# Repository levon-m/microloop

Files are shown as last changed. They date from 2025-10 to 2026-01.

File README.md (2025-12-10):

# μLoop

μLoop is a standalone **looper & sampler** quantized to external MIDI clock for real-time audio manipulation.\
\
Inspired by French House and Electro sounds, μLoop lets you create immediate **rhythmic glitches** and **sustained textures** with added performance effects.

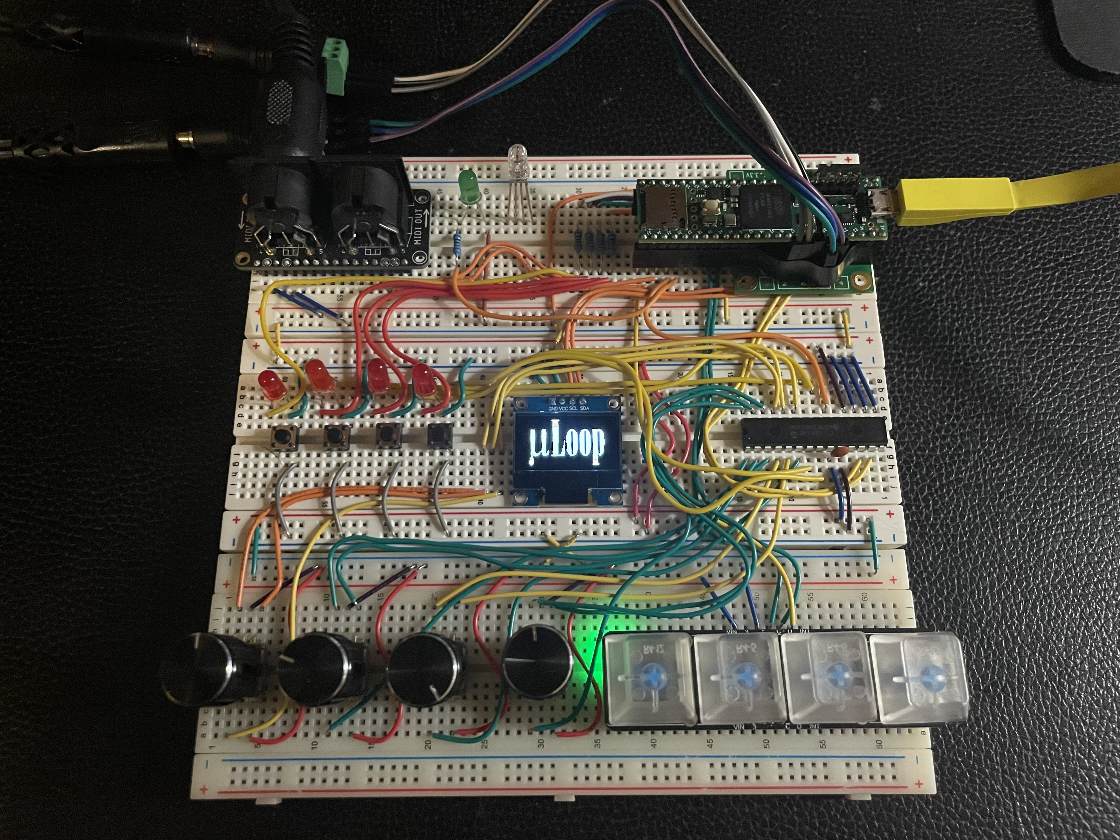
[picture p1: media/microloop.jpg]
MicroLoop Hardware


## Features

#### Effects

- **STUTTER**: Loop buffer that captures and repeats audio slices for glitchy textures
- **FREEZE**: Granular hold effect that captures and sustains a 3ms moment of audio
- **CHOKE**: Instant mute with 3ms crossfades for dramatic cuts and rhythmic gating

#### Control

- **4 Rotary Encoders**: Real-time parameter adjustment for each effect
- **4 Mechanical Switches**: Cherry MX Blue switches with RGB LED feedback
- **4 Preset Buttons**: Access to 4 slots for saving loops via microSD card

#### Interface

- **OLED Display**: Shows effect state, parameter menu system, and settings
- **RGB LED**: Visual feedback for effect states and loop capture
- **Beat LED**: Visualizes incoming jitter-smoothed MIDI clock
- **Preset LEDs**: Visualizes selected preset as well as save/delete operations

#### Timing

- **MIDI Sync**: External MIDI clock sync with <50µs jitter
- **Free & Quantized Modes**: Immediate triggering or synced onset/release for all effects
- **Quantization Grid**: Global beat divisions (1/4, 1/8, 1/16, 1/32 notes)

## Hardware

- Built around the [Teensy 4.1](https://www.pjrc.com/store/teensy41.html) (ARM Cortex-M7 @ 600 MHz)
- Stereo audio I/O via the [Teensy Audio Adapter](https://www.pjrc.com/store/teensy3_audio.html) (SGTL5000 codec @ 44.1 kHz, 16-bit, 128-sample block size)

#### Components

- Teensy 4.1 + Audio Adapter
- Adafruit MIDI FeatherWing
- Adafruit NeoKey 1X4 switches
- SSD1306 128x64 OLED Display
- CYT1100 Rotary Encoders with switches
- MCP23017 I2C I/O expander
- MicroSD Card

#### Interfaces

- **Audio**: Stereo line-in/out via 3.5mm jacks
- **MIDI**: DIN connector
- **I2C**: 3 independent buses for peripherals
- **SDIO**: High-speed 4-bit microSD interface

See [hardware/](hardware/) for full BOM and KiCAD schematics

## Software

#### Signal Flow

- Input -> Timebase -> Stutter -> Freeze -> Choke -> Output

#### Components

- **SGTL5000**: custom register-layer driver for I2C codec configuration
- **Timebase**: Centralized timing authority bridging MIDI clock and audio samples
- **Quantization API**: Sample-accurate for beat/bar-aligned recording and playback
- **Effect System**: Polymorphic command dispatch

#### Architecture

- **Audio ISR**: 128-sample blocks, zero-allocation DSP
- **App Thread**: MIDI clock processing, command dispatch, preset I/O
- **MIDI Thread**: Serial clock reception from DIN connector
- **NeoKey Thread**: Button event handling ISR and RGB LED updates
- **MCP Thread**: 4 rotary encoders via I/O expander interrupts
- **Display Thread**: OLED runtime rendering

#### Design Patterns

- **State Machines**: Deterministic effect transitions with atomic updates
- **Command Pattern**: Type-safe button -> effect communication
- **Registry Pattern**: Dynamic effect lookup and dispatch
- **Observer**: Display subscribes to effect state changes

See [libs/](libs/) for external libraries used

## Technical Highlights

- **Lock-free architecture**: Zero mutexes, all critical paths use atomics + SPSC queues
- **Zero-allocation DSP**: All buffers pre-allocated for deterministic performance
- **Quantization accuracy**: ±11µs (0.5 samples)
- **MIDI jitter**: <50µs (EMA-smoothed BPM)
- **Clean layering**: 4-tier dependency graph (Core -> HAL -> DSP -> App), no upward dependencies

## Build & Flash

#### Prerequisites

- [ARM GNU Toolchain](https://developer.arm.com/downloads/-/arm-gnu-toolchain-downloads) (bare-metal `arm-none-eabi`) 10.3+ on your `PATH`  
- [CMake](https://cmake.org/download/) 3.16+
- [Ninja](https://ninja-build.org/) 1.10+
- Teensy Loader [GUI](https://www.pjrc.com/teensy/loader.html) or [CLI](https://www.pjrc.com/teensy/loader_cli.html)

#### Build

```bash
git clone https://github.com/levon-m/microloop.git
cd microloop

# Configure and build
cmake -S . -B build -G Ninja -DCMAKE_BUILD_TYPE=Release
cmake --build build
```

This produces the firmware file:

```text
build/microloop.hex
```

#### Flash

GUI:

1. Open the Teensy Loader app

2. File -> Open HEX File -> select build/microloop.hex

3. Connect the Teensy and press Program (or the BOOT button if prompted)

CLI:

```bash
cd build
teensy_loader_cli --mcu=TEENSY41 -w microloop.hex
```

Press the Teensy BOOT button once if it doesn’t auto-detect

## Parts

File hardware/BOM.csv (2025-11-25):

Item | Quantity | RefDes | MFR / Source | MFR PN / Link | DigiKey PN | ~Price
Teensy 4.1 (with header pins) | 1 | U1 | SparkFun Electronics | 28370 | 1568-28370-ND | $29.50
Teensy Audio Adapter board Rev D | 1 | U2 | SparkFun Electronics | 15845 | 1568-15845-ND | $9.80
8 MB PSRAM chip | 1 |  | SparkFun Electronics | COM-28391 | 1568-COM-28391-ND | $2.25
MIDI FeatherWing kit | 1 | U3 | Adafruit Industries LLC | 4740 | 1528-4740-ND | $6.95
NeoKey 1X4 mechanical key switch board w/ LEDs | 1 | U7 | Adafruit Industries LLC | 4980 | 1528-4980-ND | $9.95
Cherry MX Blue switches (5-pin, transparent) | 4 |  | Cherry Americas LLC | MX2A-E1NB | 1644-MX2A-E1NB-ND | $7.00
Translucent keycaps | 1 |  | Adafruit Industries LLC | 4956 | 1528-4956-ND | $4.95
MCP23017 I2C I/O expander | 1 | U5 | Microchip Technology | MCP23017-E/SP | MCP23017-E/SP-ND | $1.69
Rotary encoders with push buttons (20 detents) + knob caps | 1 | SW1, SW2, SW3, SW4 | Amazon | https://www.amazon.com/dp/B07DM2YMT4 |  | $8.89
128GB microSD card (can go as low as 8GB) | 1 |  | Amazon | https://www.amazon.com/dp/B0B7NTY2S6 |  | $16.99
OLED I2C module (monochrome white, 128x64) | 1 | U6 | Amazon | https://www.amazon.com/dp/B09JWN8K99 |  | $12.99
Stackable (long-tail) headers | 1 |  | Amazon | https://www.amazon.com/dp/B0778M5P1W |  | $6.99
3.5mm stereo jacks to screw terminals | 1 | J1, J2 | Amazon | https://www.amazon.com/dp/B017CBTLJK |  | $5.79
Tactile Switches | 4 | SW5, SW6, SW7, SW8 | TE Connectivity ALCOSWITCH Switches | 1825910-6 | 450-1650-ND | $0.52
Green LED | 1 | D2 | Lite-On Inc. | LTL-307GE | 160-1702-ND | $0.19
Red LEDs | 4 | D3, D4, D5, D6 | Lite-On Inc. | LTL-307EE | 160-1701-ND | $0.76
RGB LED | 1 | D1 | Inolux | HV-5RGB60 | 1830-1014-ND | $1.06
330 Ohm Resistors | 8 | R1, R2, R3, R4, R5, R6, R7, R8 | Stackpole Electronics Inc | CF14JT330R | CF14JT330RCT-ND | $0.60
100 nF Capacitor | 1 | C1 | Vishay Beyschlag/Draloric/BC Components | K104K15X7RF5TL2 | BC1084CT-ND | $0.25
 |  |  |  |  |  | $127

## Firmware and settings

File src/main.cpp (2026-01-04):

#include <Arduino.h>
#include <Audio.h>
#include <TeensyThreads.h>
#include "MidiInput.h"
#include "App.h"
#include "NeokeyInput.h"
#include "Ssd1306Display.h"
#include "Mcp23017Input.h"
#include "SdCardStorage.h"
#include "FreezeAudio.h"
#include "ChokeAudio.h"
#include "StutterAudio.h"
#include "EffectManager.h"
#include "Trace.h"
#include "Timebase.h"
#include "TimebaseAudio.h"

AudioInputI2S i2s_in;
TimebaseAudio timekeeper;  // Tracks sample position
FreezeAudio freeze;    // Circular buffer freeze effect
ChokeAudio choke;      // Smooth mute effect
StutterAudio stutter;
AudioOutputI2S i2s_out;
// MOTU 3/4 line input gains are fixed and very insensitive, hearing noise floor without a boost
//AudioAmplifier outGainL;
//AudioAmplifier outGainR;

// Audio connections (stereo L+R)
AudioConnection patchCord1(i2s_in, 0, timekeeper, 0);
AudioConnection patchCord2(i2s_in, 1, timekeeper, 1);
AudioConnection patchCord3(timekeeper, 0, stutter, 0);
AudioConnection patchCord4(timekeeper, 1, stutter, 1);
AudioConnection patchCord5(stutter, 0, freeze, 0);
AudioConnection patchCord6(stutter, 1, freeze, 1);
AudioConnection patchCord7(freeze, 0, choke, 0);
AudioConnection patchCord8(freeze, 1, choke, 1);
AudioConnection patchCord9(choke, 0, i2s_out, 0);
AudioConnection patchCord10(choke, 1, i2s_out, 1);
//AudioConnection patchCord11(outGainL, 0, i2s_out, 0);
//AudioConnection patchCord12(outGainR, 0, i2s_out, 1);


// Teensy Audio Library SGTL5000 control
AudioControlSGTL5000 codec;

// Global thread IDs for debugging
int g_ioThreadId = -1;
int g_inputThreadId = -1;
int g_mcpThreadId = -1;
int g_displayThreadId = -1;
int g_appThreadId = -1;

// SD operation request from thread to main loop
// threads.stop()/start() MUST be called from main loop, not from within a thread
volatile bool g_sdOperationPending = false;
volatile uint8_t g_sdOperationSlot = 0;
volatile int g_sdOperationType = 0; // 0=none, 1=save, 2=load, 3=delete
volatile bool g_sdOperationComplete = false;
volatile int g_sdOperationResult = 0;

void ioThreadEntry() {
    MidiInput::threadLoop();  // Never returns
}

void inputThreadEntry() {
    NeokeyInput::threadLoop();  // Never returns
}

void mcpThreadEntry() {
    Mcp23017Input::threadLoop();  // Never returns
}

void displayThreadEntry() {
    Ssd1306Display::threadLoop();  // Never returns
}

void appThreadEntry() {
    App::threadLoop();  // Never returns
}

void setup() {
    Serial.begin(115200);

    // Print crash report if available (from previous run)
    // DEBUGGING AID: If Teensy crashed, this tells us why
    if (CrashReport) {
        Serial.print(CrashReport);
    }

    Serial.println("=== MicroLoop Initializing ===");

    AudioMemory(60);

    if (!codec.enable()) {
        Serial.println("ERROR: Codec init failed!");
        while (1) {
            // Blink LED rapidly to indicate error
            digitalWrite(LED_BUILTIN, !digitalRead(LED_BUILTIN));
            delay(100);
        }
    }

    // Configure for line-in and line-out operation
    // IMPORTANT: Use MOTU M4 **REAR LINE INPUTS 3-4** (not front combo jacks!)
    codec.inputSelect(AUDIO_INPUT_LINEIN);  // Use line-in (not mic)
    codec.micGain(0);
    codec.lineInLevel(0);  // Line-in gain: 0-15 (0 = 3.12V p-p, lowest gain to prevent clipping)
    codec.lineOutLevel(13);  // Line-out level: 13-31 (13 = 1.31V p-p, standard line level)
    codec.unmuteLineout();  // Unmute line-out
    codec.volume(0.7);  // Headphone volume (0.0-1.0) - start low to avoid clipping
    codec.unmuteHeadphone();  // Unmute headphone (for testing)
    //outGainL.gain(1.0f);   // try 1.5 to 3.0
    //outGainR.gain(1.0f);

    Serial.println("Audio: OK (using Teensy Audio Library SGTL5000)");

    Timebase::begin();
    Serial.println("TimeKeeper: OK");

    MidiInput::begin();
    Serial.println("MIDI: OK (DIN on Serial8)");

    // Initialize SD card BEFORE App::begin() (PresetController needs it)
    if (!SdCardStorage::begin()) {
        Serial.println("WARNING: SD card init failed (presets disabled)");
        // Continue anyway - SD card is optional for basic functionality
    } else {
        Serial.println("SD Card: OK (SDIO)");
    }

    App::begin();
    Serial.println("App Logic: OK");

    if (!NeokeyInput::begin()) {
        Serial.println("ERROR: NeoKey I/O init failed!");
        while (1) {
            // Blink LED rapidly to indicate error
            digitalWrite(LED_BUILTIN, !digitalRead(LED_BUILTIN));
            delay(100);
        }
    }
    Serial.println("NeoKey I/O: OK (Neokey on I2C 0x30 / Wire2)");

    if (!Mcp23017Input::begin()) {
        Serial.println("ERROR: MCP I/O init failed!");
        while (1) {
            // Blink LED rapidly to indicate error
            digitalWrite(LED_BUILTIN, !digitalRead(LED_BUILTIN));
            delay(100);
        }
    }
    Serial.println("MCP I/O: OK (MCP23017 on I2C 0x20 / Wire, ISR capture mode)");

    if (!Ssd1306Display::begin()) {
        Serial.println("WARNING: Display init failed (will continue without display)");
        // Continue anyway - display is optional for basic functionality
    } else {
        Serial.println("Display: OK (SSD1306 on I2C 0x3C / Wire1)");
    }

    if (!EffectManager::registerEffect(EffectID::STUTTER, &stutter)) {
        Serial.println("FATAL: Failed to register stutter effect!");
        while (1) {
            // Blink LED rapidly to indicate error
            digitalWrite(LED_BUILTIN, !digitalRead(LED_BUILTIN));
            delay(100);
        }
    }
    if (!EffectManager::registerEffect(EffectID::FREEZE, &freeze)) {
        Serial.println("FATAL: Failed to register freeze effect!");
        while (1) {
            // Blink LED rapidly to indicate error
            digitalWrite(LED_BUILTIN, !digitalRead(LED_BUILTIN));
            delay(100);
        }
    }
    if (!EffectManager::registerEffect(EffectID::CHOKE, &choke)) {
        Serial.println("FATAL: Failed to register choke effect!");
        while (1) {
            // Blink LED rapidly to indicate error
            digitalWrite(LED_BUILTIN, !digitalRead(LED_BUILTIN));
            delay(100);
        }
    }
    Serial.print("Effect Manager: Registered ");
    Serial.print(EffectManager::getNumEffects());
    Serial.println(" effect(s)");

    g_ioThreadId = threads.addThread(ioThreadEntry, 0, 2048);
    g_inputThreadId = threads.addThread(inputThreadEntry, 0, 2048);
    g_mcpThreadId = threads.addThread(mcpThreadEntry, 0, 2048);
    g_displayThreadId = threads.addThread(displayThreadEntry, 0, 2048);
    // 16KB stack: App thread runs blocking SD save/load/delete operations
    g_appThreadId = threads.addThread(appThreadEntry, 0, 16384);

    if (g_ioThreadId < 0 || g_inputThreadId < 0 || g_mcpThreadId < 0 || g_displayThreadId < 0 || g_appThreadId < 0) {
        Serial.println("ERROR: Thread creation failed!");
        while (1);  // Halt
    }

    // threads.setTimeSlice(ioThreadId, 2);   // 2ms - very responsive
    // threads.setTimeSlice(appThreadId, 5);  // 5ms - moderate

    Serial.println("Threads: Started");
    Serial.println("=== MicroLoop Running ===");
    Serial.println();
    Serial.println("Commands:");
    Serial.println("  't' - Dump trace buffer");
    Serial.println("  'c' - Clear trace buffer");
    Serial.println("  's' - Show TimeKeeper status");
    Serial.println();
}

void loop() {
    // Thread state monitoring - print every second
    static uint32_t lastThreadStatePrint = 0;
    if (millis() - lastThreadStatePrint >= 1000) {
        lastThreadStatePrint = millis();

        auto printState = [](const char* name, int id) {
            Serial.print(" ");
            Serial.print(name);
            Serial.print("=");
            if (id >= 0) {
                int state = threads.getState(id);
                Serial.print(state);
                // Decode state: 0=RUNNING, 1=SUSPENDED, 2=ENDED, etc.
                Serial.print("(");
                switch(state) {
                    case 0: Serial.print("RUN"); break;
                    case 1: Serial.print("SUSP"); break;
                    case 2: Serial.print("END"); break;
                    default: Serial.print("???"); break;
                }
                Serial.print(")");
            } else {
                Serial.print("N/A");
            }
        };

        Serial.print("[ThreadStates] T=");
        Serial.print(millis());
        printState(" app", g_appThreadId);
        printState(" io", g_ioThreadId);
        printState(" nk", g_inputThreadId);
        printState(" mcp", g_mcpThreadId);
        printState(" disp", g_displayThreadId);
        Serial.println();
    }

    // Check for serial commands (non-blocking)
    if (Serial.available()) {
        char cmd = Serial.read();
        switch (cmd) {
            case 't':  // Dump trace buffer
                Serial.println("\n[Dumping trace buffer...]");
                Trace::dump();
                break;

            case 'c':  // Clear trace buffer
                Serial.println("\n[Clearing trace buffer...]");
                Trace::clear();
                Serial.println("Trace buffer cleared.");
                break;

            case 's':  // Show TimeKeeper status
                Serial.println("\n=== TimeKeeper Status ===");
                Serial.print("Sample Position: ");
                Serial.println((uint32_t)Timebase::getSamplePosition());  // Print low 32 bits
                Serial.print("Beat: ");
                Serial.print(Timebase::getBeatNumber());
                Serial.print(" (Bar ");
                Serial.print(Timebase::getBarNumber());
                Serial.print(", Beat ");
                Serial.print(Timebase::getBeatInBar());
                Serial.print(", Tick ");
                Serial.print(Timebase::getTickInBeat());
                Serial.println(")");
                Serial.print("BPM: ");
                Serial.println(Timebase::getBPM(), 2);
                Serial.print("Samples/Beat: ");
                Serial.println(Timebase::getSamplesPerBeat());
                Serial.print("Transport: ");
                switch (Timebase::getTransportState()) {
                    case Timebase::TransportState::STOPPED: Serial.println("STOPPED"); break;
                    case Timebase::TransportState::PLAYING: Serial.println("PLAYING"); break;
                    case Timebase::TransportState::RECORDING: Serial.println("RECORDING"); break;
                }
                Serial.print("Samples to next beat: ");
                Serial.println(Timebase::samplesToNextBeat());
                Serial.print("Samples to next bar: ");
                Serial.println(Timebase::samplesToNextBar());
                Serial.println("=========================\n");
                break;

            case '\n':
            case '\r':
                // Ignore newlines
                break;

            default:
                Serial.print("Unknown command: ");
                Serial.println(cmd);
                Serial.println("Commands: 't' (dump trace), 'c' (clear trace), 's' (status)");
                break;
        }
    }

    delay(10);  // Don't hog CPU
}

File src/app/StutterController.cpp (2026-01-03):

#include "StutterController.h"
#include "NeokeyInput.h"
#include "DisplayManager.h"
#include "Timebase.h"
#include "EncoderHandler.h"
#include <Arduino.h>

// ========== RGB LED PIN DEFINITIONS ==========
static constexpr uint8_t RGB_LED_R_PIN = 28;  // Red (PWM capable)
static constexpr uint8_t RGB_LED_G_PIN = 36;  // Green (PWM capable)
static constexpr uint8_t RGB_LED_B_PIN = 37;  // Blue (PWM capable)

// ========== GAMMA LOOKUP TABLE (γ=4.0) ==========
// Pre-computed gamma curve for dramatic LED brightness ramp.
// Input: linear progress 0-255, Output: gamma-corrected brightness 0-255
// Formula: output = 255 * (input/255)^4.0
// Characteristic: stays dim until ~80%, then rapid ramp in final ~20%
static constexpr uint8_t GAMMA_LUT[256] = {
      0,   0,   0,   0,   0,   0,   0,   0,   0,   0,   0,   0,   0,   0,   0,   0,
      0,   0,   0,   0,   0,   0,   0,   0,   0,   0,   0,   0,   0,   0,   0,   0,
      0,   0,   0,   0,   0,   0,   0,   0,   0,   0,   0,   0,   0,   0,   0,   0,
      0,   0,   0,   0,   0,   0,   0,   0,   0,   0,   0,   0,   0,   0,   0,   0,
      0,   0,   0,   0,   0,   0,   0,   0,   0,   0,   0,   1,   1,   1,   1,   1,
      1,   1,   1,   1,   1,   1,   1,   1,   1,   1,   2,   2,   2,   2,   2,   2,
      2,   2,   3,   3,   3,   3,   3,   3,   4,   4,   4,   4,   4,   5,   5,   5,
      5,   6,   6,   6,   6,   7,   7,   7,   8,   8,   8,   9,   9,   9,  10,  10,
     11,  11,  11,  12,  12,  13,  13,  14,  14,  15,  15,  16,  17,  17,  18,  18,
     19,  20,  20,  21,  22,  22,  23,  24,  25,  25,  26,  27,  28,  29,  30,  31,
     31,  32,  33,  34,  35,  36,  38,  39,  40,  41,  42,  43,  45,  46,  47,  48,
     50,  51,  52,  54,  55,  57,  58,  60,  61,  63,  64,  66,  68,  69,  71,  73,
     75,  76,  78,  80,  82,  84,  86,  88,  90,  92,  94,  96,  98, 100, 103, 105,
    107, 109, 112, 114, 117, 119, 122, 124, 127, 129, 132, 135, 137, 140, 143, 146,
    149, 151, 154, 157, 160, 163, 166, 170, 173, 176, 179, 182, 186, 189, 192, 196,
    199, 203, 206, 210, 214, 217, 221, 225, 228, 232, 236, 240, 244, 248, 252, 255
};

/**
 * Calculate LED brightness for wait states using gamma-corrected ramp
 *
 * @param currentSample Current audio sample position
 * @param startSample Sample position when wait began
 * @param targetSample Sample position when wait will end
 * @param rampUp true = 0→max (onset waits), false = max→0 (end waits)
 * @return Gamma-corrected brightness value 0-255
 */
static uint8_t calculateWaitBrightness(uint64_t currentSample, uint64_t startSample,
                                       uint64_t targetSample, bool rampUp) {
    // Safety checks
    if (targetSample <= startSample) return rampUp ? 255 : 0;
    if (currentSample <= startSample) return rampUp ? 0 : 255;
    if (currentSample >= targetSample) return rampUp ? 255 : 0;

    // Calculate linear progress (0-255 range for LUT indexing)
    uint64_t elapsed = currentSample - startSample;
    uint64_t total = targetSample - startSample;
    uint8_t linearProgress = static_cast<uint8_t>((elapsed * 255) / total);

    // Apply gamma curve
    uint8_t gammaBrightness = GAMMA_LUT[linearProgress];

    // Invert for ramp down
    return rampUp ? gammaBrightness : (255 - gammaBrightness);
}

StutterController::StutterController(StutterAudio& effect)
    : m_effect(effect),
      m_currentParameter(Parameter::ONSET),  // Default to ONSET (first in cycle)
      m_funcHeld(false),
      m_stutterHeld(false),
      m_wasEnabled(false),
      m_captureCompleteCallback(nullptr),
      m_lastState(StutterState::IDLE_NO_LOOP),
      m_captureInProgress(false) {
}

BitmapID StutterController::stateToBitmap(StutterState state) {
    // Only show STUTTER_ACTIVE during playback states
    switch (state) {
        case StutterState::PLAYING:
        case StutterState::WAIT_PLAYBACK_LENGTH:
            return BitmapID::STUTTER_ACTIVE;
        default:
            return BitmapID::DEFAULT;  // All other states (idle, capture, wait onset)
    }
}

const char* StutterController::onsetName(StutterOnset onset) {
    switch (onset) {
        case StutterOnset::FREE:      return "Free";
        case StutterOnset::QUANTIZED: return "Quantized";
        default: return "Free";
    }
}

const char* StutterController::lengthName(StutterLength length) {
    switch (length) {
        case StutterLength::FREE:      return "Free";
        case StutterLength::QUANTIZED: return "Quantized";
        default: return "Free";
    }
}

const char* StutterController::captureStartName(StutterCaptureStart captureStart) {
    switch (captureStart) {
        case StutterCaptureStart::FREE:      return "Free";
        case StutterCaptureStart::QUANTIZED: return "Quantized";
        default: return "Free";
    }
}

const char* StutterController::captureEndName(StutterCaptureEnd captureEnd) {
    switch (captureEnd) {
        case StutterCaptureEnd::FREE:      return "Free";
        case StutterCaptureEnd::QUANTIZED: return "Quantized";
        default: return "Free";
    }
}

// ========== BUTTON PRESS HANDLER ==========
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

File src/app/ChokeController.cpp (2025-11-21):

#include "ChokeController.h"
#include "NeokeyInput.h"
#include "DisplayManager.h"
#include "Timebase.h"
#include "EncoderHandler.h"
#include <Arduino.h>

ChokeController::ChokeController(ChokeAudio& effect)
    : m_effect(effect),
      m_currentParameter(Parameter::LENGTH),
      m_wasEnabled(false) {
}

const char* ChokeController::lengthName(ChokeLength length) {
    switch (length) {
        case ChokeLength::FREE:      return "Free";
        case ChokeLength::QUANTIZED: return "Quantized";
        default: return "Free";
    }
}

const char* ChokeController::onsetName(ChokeOnset onset) {
    switch (onset) {
        case ChokeOnset::FREE:      return "Free";
        case ChokeOnset::QUANTIZED: return "Quantized";
        default: return "Free";
    }
}

bool ChokeController::handleButtonPress(const Command& cmd) {
    if (cmd.targetEffect != EffectID::CHOKE) {
        return false;  // Not our effect
    }

    if (cmd.type != CommandType::EFFECT_ENABLE && cmd.type != CommandType::EFFECT_TOGGLE) {
        return false;  // Not a press command
    }

    ChokeLength lengthMode = m_effect.getLengthMode();
    ChokeOnset onsetMode = m_effect.getOnsetMode();

    if (onsetMode == ChokeOnset::FREE) {
        // FREE ONSET: Engage immediately
        m_effect.enable();

        if (lengthMode == ChokeLength::QUANTIZED) {
            // FREE ONSET + QUANTIZED LENGTH
            Quantization quant = EffectQuantization::getGlobalQuantization();
            uint32_t durationSamples = EffectQuantization::calculateQuantizedDuration(quant);
            uint64_t releaseSample = Timebase::getSamplePosition() + durationSamples;
            m_effect.scheduleRelease(releaseSample);

            Serial.print("Choke ENGAGED (Free onset, Quantized length=");
            Serial.print(EffectQuantization::quantizationName(quant));
            Serial.println(")");
        } else {
            // FREE ONSET + FREE LENGTH
            Serial.println("Choke ENGAGED (Free onset, Free length)");
        }

        // Update visual feedback
        NeokeyInput::setLED(EffectID::CHOKE, true);
        DisplayManager::instance().updateDisplay();
        return true;  // Command handled
    } else {
        // QUANTIZED ONSET: Schedule for next boundary with lookahead offset
        Quantization quant = EffectQuantization::getGlobalQuantization();

        // DEBUG: Get all timing info
        uint64_t currentSample = Timebase::getSamplePosition();
        uint32_t samplesPerBeat = Timebase::getSamplesPerBeat();
        uint32_t beatNumber = Timebase::getBeatNumber();
        uint32_t tickInBeat = Timebase::getTickInBeat();

        uint32_t samplesToNext = EffectQuantization::samplesToNextQuantizedBoundary(quant);

        // Apply lookahead offset (fire early to catch external audio transients)
        uint32_t lookahead = EffectQuantization::getLookaheadOffset();
        uint32_t adjustedSamples = (samplesToNext > lookahead) ? (samplesToNext - lookahead) : 0;

        // Calculate absolute sample position for onset
        uint64_t onsetSample = currentSample + adjustedSamples;

        // Schedule onset in ISR (same as how length scheduling works)
        m_effect.scheduleOnset(onsetSample);

        // If length is also quantized, schedule release from onset position
        if (lengthMode == ChokeLength::QUANTIZED) {
            uint32_t durationSamples = EffectQuantization::calculateQuantizedDuration(quant);
            uint64_t releaseSample = onsetSample + durationSamples;
            m_effect.scheduleRelease(releaseSample);
        }

        Serial.print("ONSET DEBUG: currentSample=");
        Serial.print((uint32_t)currentSample);
        Serial.print(" beat=");
        Serial.print(beatNumber);
        Serial.print(" tick=");
        Serial.print(tickInBeat);
        Serial.print(" spb=");
        Serial.print(samplesPerBeat);
        Serial.print(" samplesToNext=");
        Serial.print(samplesToNext);
        Serial.print(" lookahead=");
        Serial.print(lookahead);
        Serial.print(" adjusted=");
        Serial.print(adjustedSamples);
        Serial.print(" onsetSample=");
        Serial.println((uint32_t)onsetSample);

        return true;  // Command handled
    }
}

bool ChokeController::handleButtonRelease(const Command& cmd) {
    if (cmd.targetEffect != EffectID::CHOKE) {
        return false;  // Not our effect
    }

    if (cmd.type != CommandType::EFFECT_DISABLE) {
        return false;  // Not a release command
    }

    ChokeLength lengthMode = m_effect.getLengthMode();

    if (lengthMode == ChokeLength::QUANTIZED) {
        // QUANTIZED LENGTH: Ignore release (auto-releases)
        Serial.println("Choke button released (ignored - quantized length)");
        return true;  // Command handled (skip default disable)
    }

    // FREE LENGTH: Check if we have scheduled onset via ISR API
    // QUANTIZED ONSET + FREE LENGTH: Cancel scheduled onset
    m_effect.cancelScheduledOnset();
    Serial.println("Choke scheduled onset CANCELLED (button released before beat)");

    // FREE ONSET + FREE LENGTH: Fall through to default disable
    return false;  // Let EffectManager handle disable
}
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

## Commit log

2025-09-24 fixed float print stack overflow
2025-10-06 timekeeper, trace, and tests
2025-10-10 working choke w/ timing issues + no headphone output
    [main.cpp]
2025-10-12 changed beat led to reflect timekeeper status, not tick count
2025-10-12 changed choke key, leds still not working
    [input_io.cpp]
2025-10-12 improved led tracking
2025-10-14 using teensy sgtl5000 setup
2025-10-14 encoders tested via serial
2025-10-15 added encoders to main
2025-10-30 added lookahead offset for quant, fixed oled flickering
    [choke_handler.cpp, freeze_handler.cpp]
2025-11-16 optimized encoder ISR
2025-11-16 encoder ISR fiddling + renamed encoder_menu
2025-11-16 added rgb led + switched pins around
2025-11-16 encoders updating menu at speed
2025-11-17 updated schematic
    [microloop.kicad_sch]
2025-11-17 fixed display priority with menu, fixing bitmap debouncing
    [display_io.cpp]
2025-11-17 stutter menu added, push button finnicky
2025-11-17 rising edge detection to encoder push buttons
2025-11-17 encoder push buttons almost working, still missing some presses
2025-11-17 original double trigger encoder bug
2025-11-17 encoder misses some presses, very rarely
2025-11-18 restructured repo
    [microloop.kicad_sch]
2025-11-18 finalized schematic, added bom
    [microloop.kicad_sch, microloop_bom.csv]
2025-11-18 added sd card to bom + schematic
    [microloop.kicad_sch, microloop_bom.csv]
2025-11-19 fixed capture start button mapping
2025-11-20 updated folder structure, updated stutter state machine, deleted span
    [BOM.csv]
2025-11-23 spsc queue for preset thread
2025-11-23 fixed states in presets
    [PresetController.cpp, StutterController.cpp]
2025-11-25 cleaned up presets, updated hardware
    [BOM.csv, microloop.kicad_sch]
2025-11-27 added libraries, changed README
    [microloop.kicad_sch]
2025-12-10 changed stutter waitFor state rgb indicator to pwm
2026-01-03 fixed stutter bitmap state displays + changed freeze amount
    [FreezeAudio.h, StutterController.cpp]
